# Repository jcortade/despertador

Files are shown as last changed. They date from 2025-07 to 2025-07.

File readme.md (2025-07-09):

# Alarm clock based on ESP32

This is an alarm clock based on ESP32 programmed in micropython. Its main features are:

- Four digits seven segments display. Oldie but goodie.
- Three push buttons for alarm time selection.
- LM386 audio power amplifier with a 1W speaker. It plays Tetris tune.
- LDR used to power off the display in the dark.
- PIR detector to see time in the dark and turn off the alarm.
- "Dimmable" LED using PWM ouput.
- It connects via wifi to an NTP server and synchronize automatically. It also even calculates summer/winter time!

Prototyping phase:
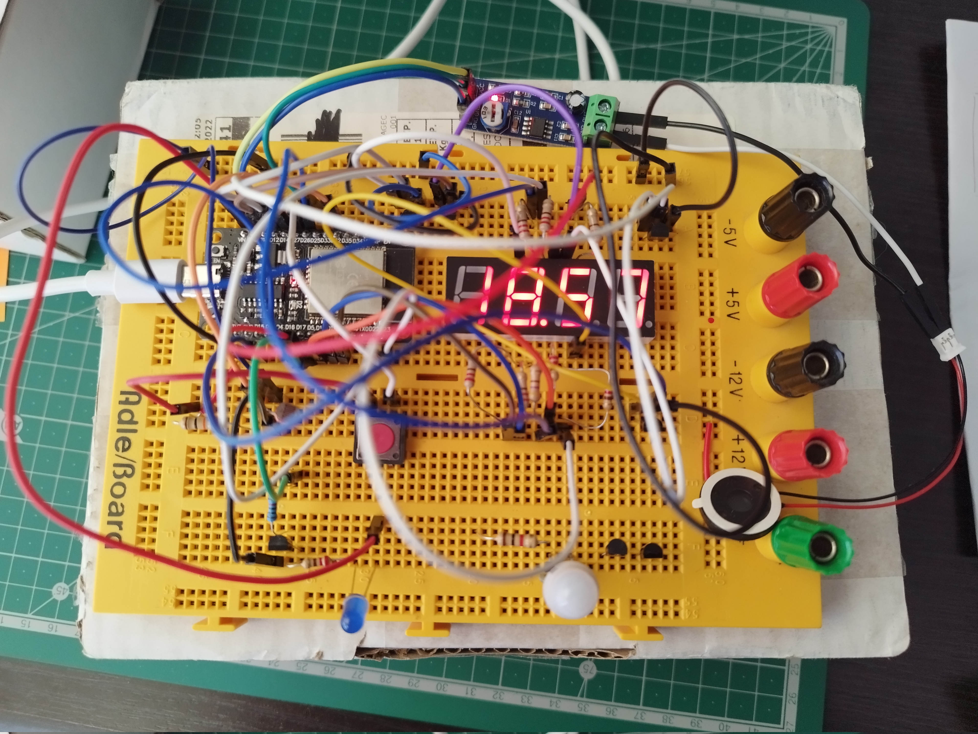
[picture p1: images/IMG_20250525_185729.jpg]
Protoboard with a mess of wiring


Preparing PCB for solder paste application:
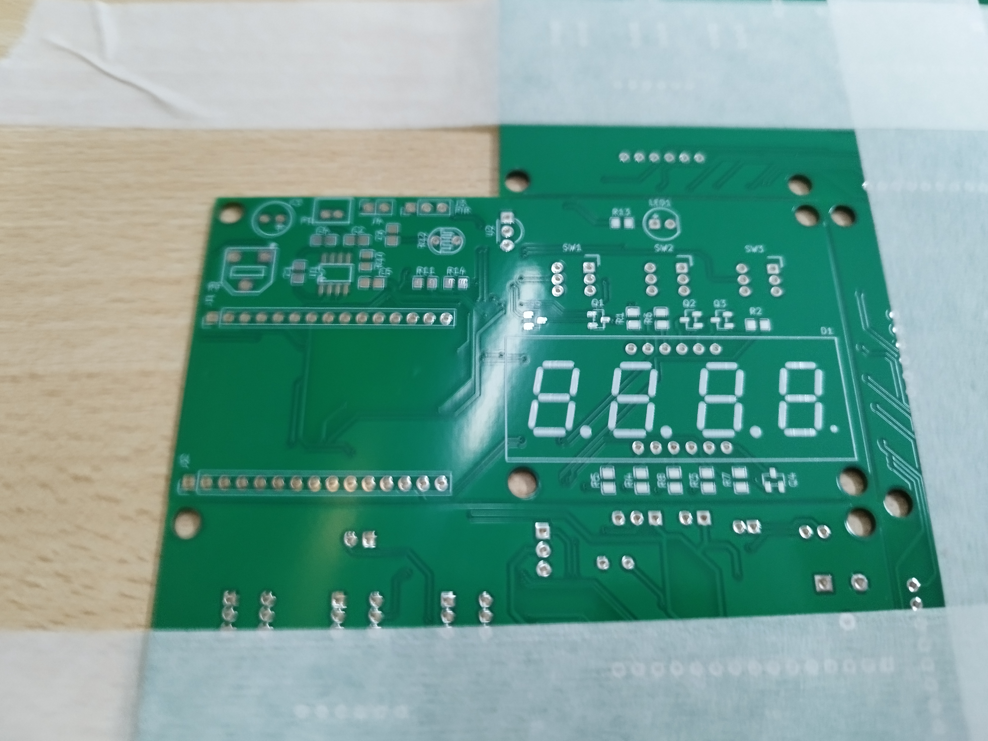
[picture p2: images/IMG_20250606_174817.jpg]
PCB


PCB with components soldered:
PCB with all components soldered

Final result:
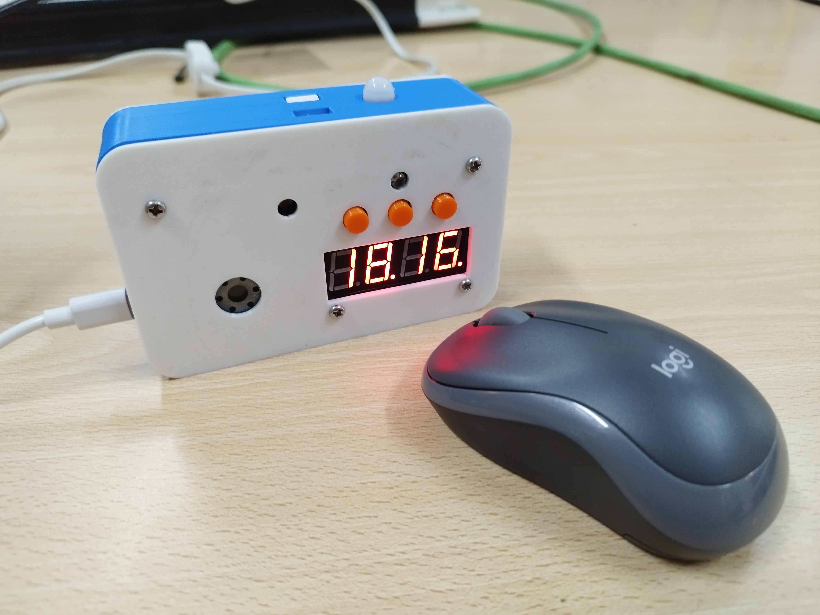
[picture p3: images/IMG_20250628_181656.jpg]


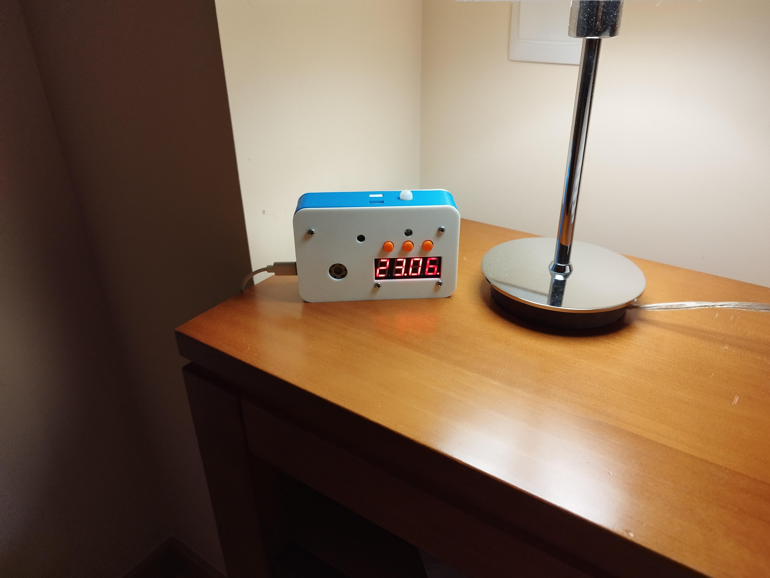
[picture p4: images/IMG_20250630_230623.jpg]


PCB was designed with kiCAD. 

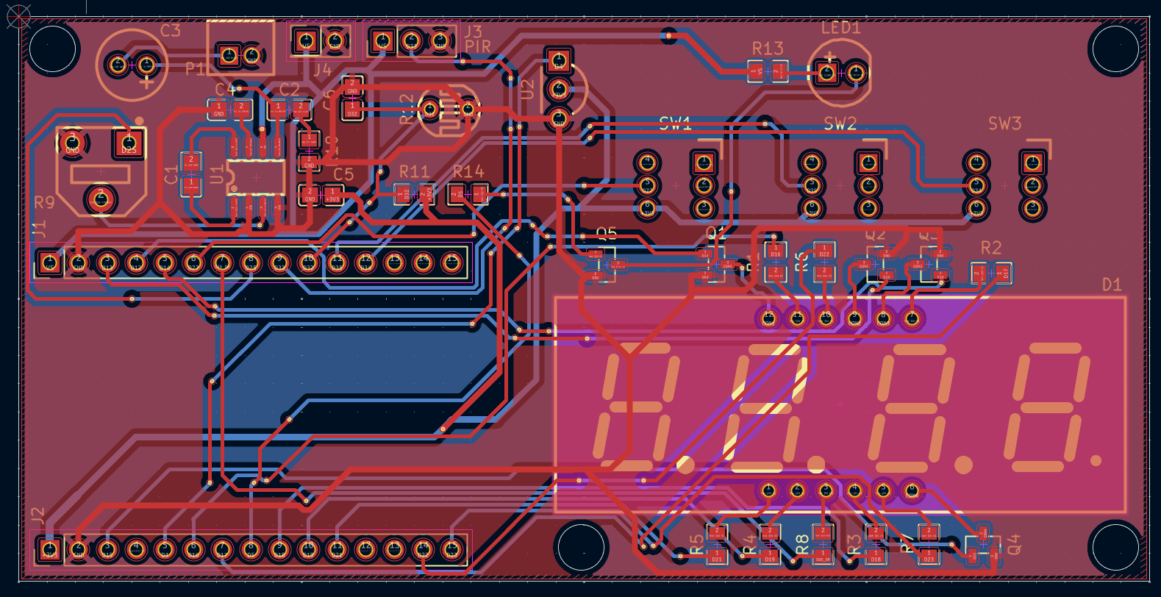
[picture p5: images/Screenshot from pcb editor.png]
PCB editor screenshot


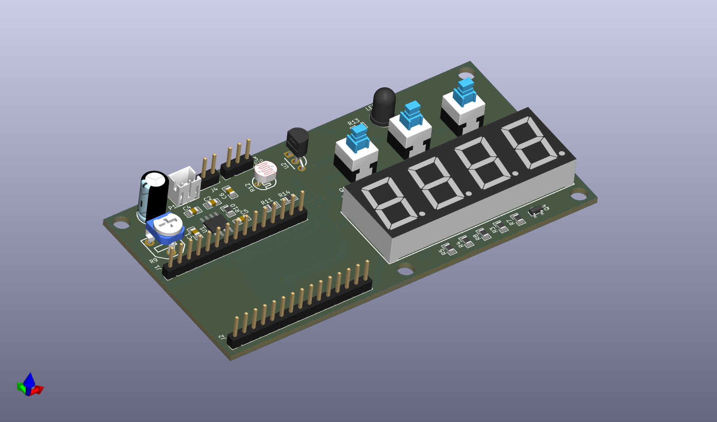
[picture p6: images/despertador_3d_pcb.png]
3D PCB visualizer screenshot


3D printed alarm clock body was designed with FreeCAD. 

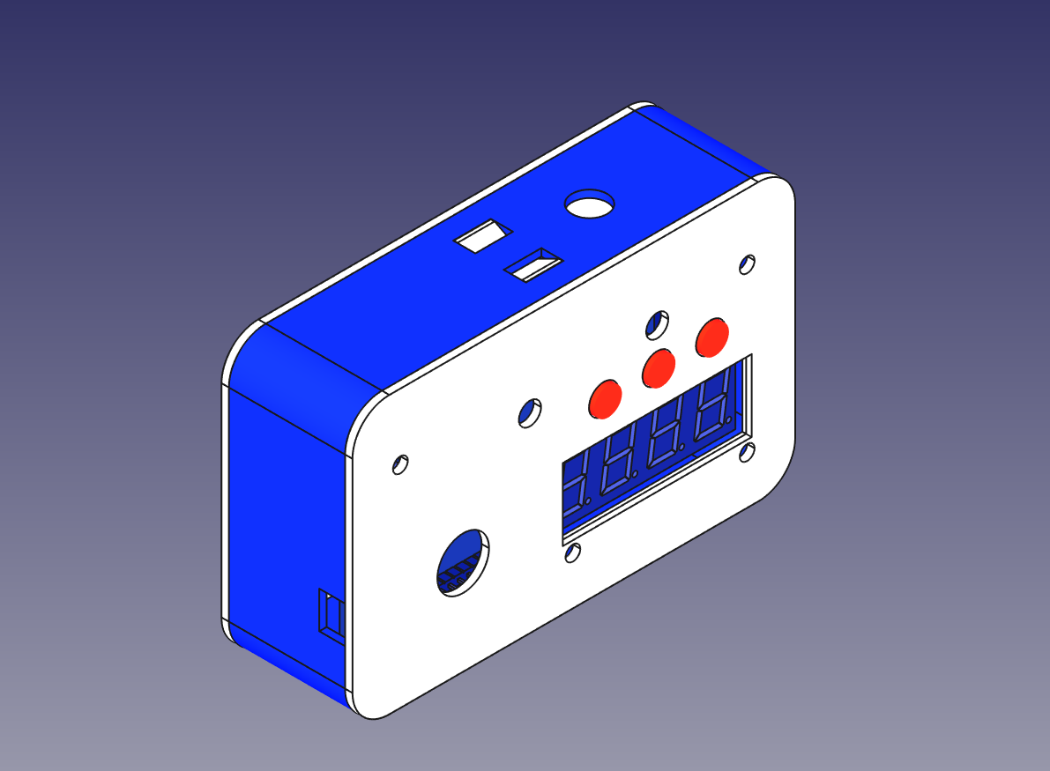
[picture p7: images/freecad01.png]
FreeCAD Screenshot 1


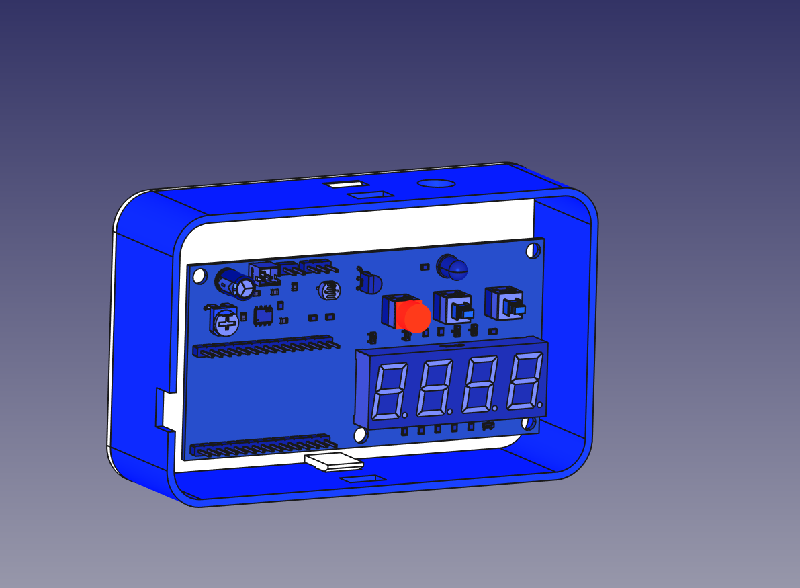
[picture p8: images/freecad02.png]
FreeCAD Screenshot 2


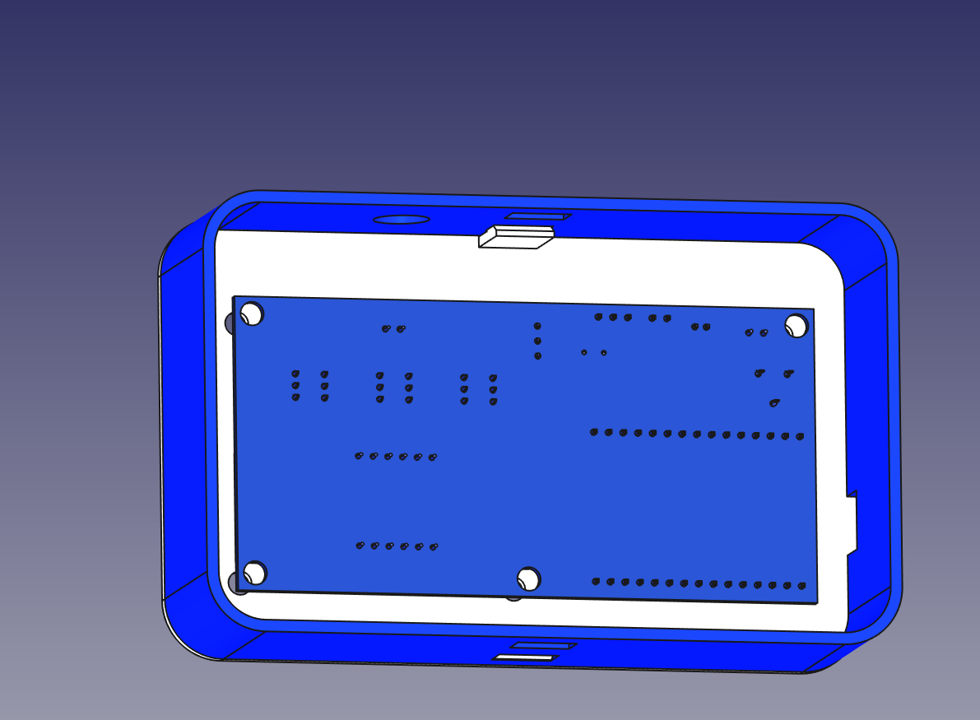
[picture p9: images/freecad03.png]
FreeCAD Screenshot 3


Inspired by this project: https://github.com/thedalles77/Raspberry-Pi-Pico-LED-Alarm-Clock

Audio player idea from here: https://circuitdigest.com/microcontroller-projects/esp32-based-audio-player

Tetris tune acknowledgements: https://assets.codeclubau.org/assets/tetris-theme.pdf

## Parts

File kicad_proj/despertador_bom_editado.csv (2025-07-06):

Reference | LCSC Part | Value | Footprint | Datasheet | Qty | LCSC Part
C1,C4 | C15850 | CL21A106KAYNNNE | easyeda2kicad:C0805 | https://lcsc.com/product-detail/Multilayer-Ceramic-Capacitors-MLCC-SMD-SMT_SAMSUNG_CL21A106KAYNNNE_10uF-106-10-25V_C15850.html | 2 | C15850
C2 | C53134 | CL21B473KBCNNNC | easyeda2kicad:C0805 | https://lcsc.com/product-detail/Multilayer-Ceramic-Capacitors-MLCC-SMD-SMT_SAMSUNG_CL21B473KBCNNNC_47nF-473-10-50V_C53134.html | 1 | C53134
C3 | C43340 | 220uF 16V 6.3*7 | easyeda2kicad:CAP-TH_BD6.3-P2.50-D1.0-FD | https://lcsc.com/product-detail/Aluminum-Electrolytic-Capacitors-Leaded_220uF-16V_C43340.html | 1 | C43340
C5,C6 | C5451689 | C0805X104K251T | easyeda2kicad:C0805 |  | 2 | C5451689
D1 | C54396 | FJ5461AH red | easyeda2kicad:LED-SEG-TH_FJ5461AH | https://lcsc.com/product-detail/Led-Segment-Display_4Bit0-56Inch-red-digital-LED-RHOS_C54396.html | 1 | C54396
LED1 | C7470729 | DY-324SVRC-H23-P-A4(FH) | easyeda2kicad:LED-TH_BD5.8-P2.54-RD |  | 1 | C7470729
P1 | C2319 | PH-2A_C2319 | easyeda2kicad:CONN-TH_2P-P2.00_PH-2A_C2319 | https://lcsc.com/product-detail/PH-Connectors_PH-2A_C2319.html | 1 | C2319
Q1,Q2,Q3,Q4 | C5236685 | BS170FTA_C5236685 | easyeda2kicad:SOT-23-3_L2.9-W1.3-P1.90-LS2.4-BR |  | 4 | C5236685
Q5 | C2150 | SS8050_C2150 | easyeda2kicad:SOT-23-3_L2.9-W1.3-P1.90-LS2.4-BR | https://lcsc.com/product-detail/Transistors-NPN-PNP_SS8050-Y1-200-350_C2150.html | 1 | C2150
R1,R2,R3,R4,R5,R6,R7,R8,R13 | C17630 | 0805W8F3300T5E | easyeda2kicad:R0805 | https://lcsc.com/product-detail/Chip-Resistor-Surface-Mount-UniOhm_330R-3300-1_C17630.html | 9 | C17630
R9 | C5205021 | RM065-103(10K) | easyeda2kicad:RES-ADJ-SMD_RM065-V1 |  | 1 | C5205021
R10 | C17415 | 0805W8F100JT5E | easyeda2kicad:R0805_NEW | https://lcsc.com/product-detail/Chip-Resistor-Surface-Mount-UniOhm_10R-10R0-1_C17415.html | 1 | C17415
R11,R14 | C17414 | 0805W8F1002T5E | easyeda2kicad:R0805 | https://lcsc.com/product-detail/Chip-Resistor-Surface-Mount-UniOhm_10KR-1002-1_C17414.html | 2 | C17414
R12 | C125626 | GL5516 | easyeda2kicad:RES-TH_L5.1-W4.3-P3.40-D0.5 | https://lcsc.com/product-detail/Photoresistors_GL5516_C125626.html | 1 | C125626
SW1,SW2,SW3 | C22363820 | PS-7054DVB-6PN | easyeda2kicad:SW-TH_6P-L7.0-W7.0-P2.00 |  | 3 | C22363820
U1 | C85119 | LM386G-S08-R | easyeda2kicad:SOP-8_L4.9-W3.9-P1.27-LS6.0-BL | https://lcsc.com/product-detail/Audio-OpAmps_LM386G-S08-R_C85119.html | 1 | C85119
U2 | C5692995 | TMP36GT9Z(UMW) | easyeda2kicad:TO-92-3_L4.8-W3.7-P2.54-L |  | 1 | C5692995

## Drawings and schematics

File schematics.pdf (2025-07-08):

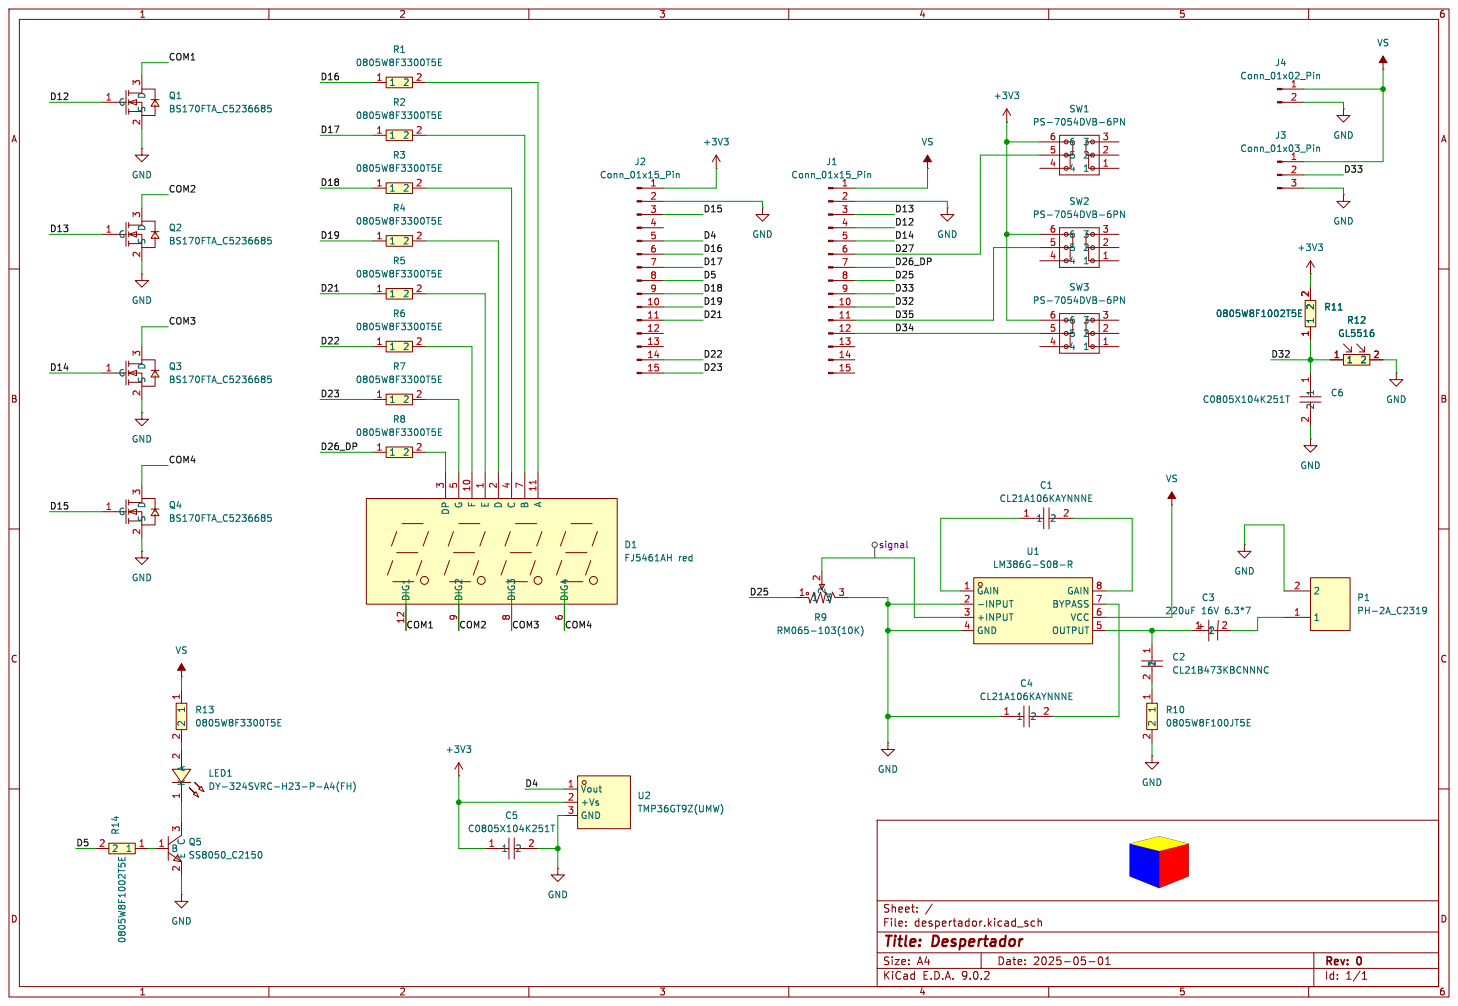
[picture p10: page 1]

Id: 1/1 Title: Despertador File: despertador.kicad_sch Sheet: /

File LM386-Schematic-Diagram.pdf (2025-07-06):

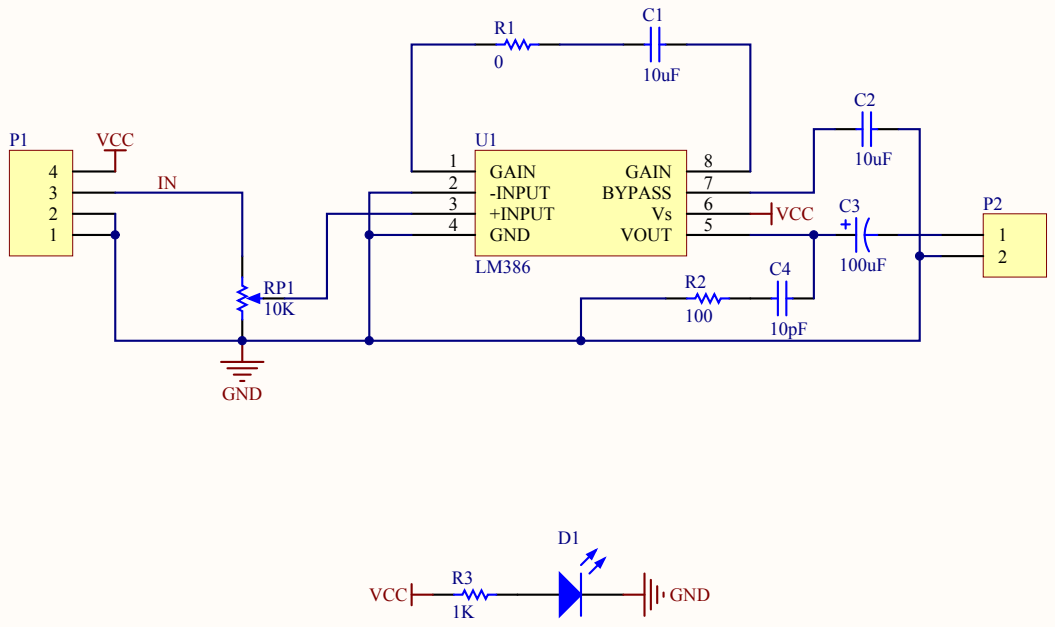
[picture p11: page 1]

Comment | Description | Designator | Footprint | LibRef | Quantity
10uF | Capacitor | C1, C2 | 0805 | CAP | 2
100uF | Polarized Capacitor (Radial) | C3 | CAPPR2-5x6.8 | Cap Pol1 | 1
10pF | Capacitor | C4 | 0805 | CAP | 1
LED | Typical INFRARED GaAs LED | D1 | LED-0805 | LED | 1
Header 4 | Header, 4-Pin | P1 | HDR1X4 | Header 4 | 1
Header 2 | Header, 2-Pin | P2 | Terminal-5.08-2P | Header 2 | 1
0 | Semiconductor Resistor | R1 | 0805 | RES | 1
100 | Semiconductor Resistor | R2 | 0805 | RES | 1
1K | Semiconductor Resistor | R3 | 0805 | RES | 1
10K | Potentiometer | RP1 | RM063 | RPot | 1
LM386 | | U1 | SOIC8 | LM386 | 1

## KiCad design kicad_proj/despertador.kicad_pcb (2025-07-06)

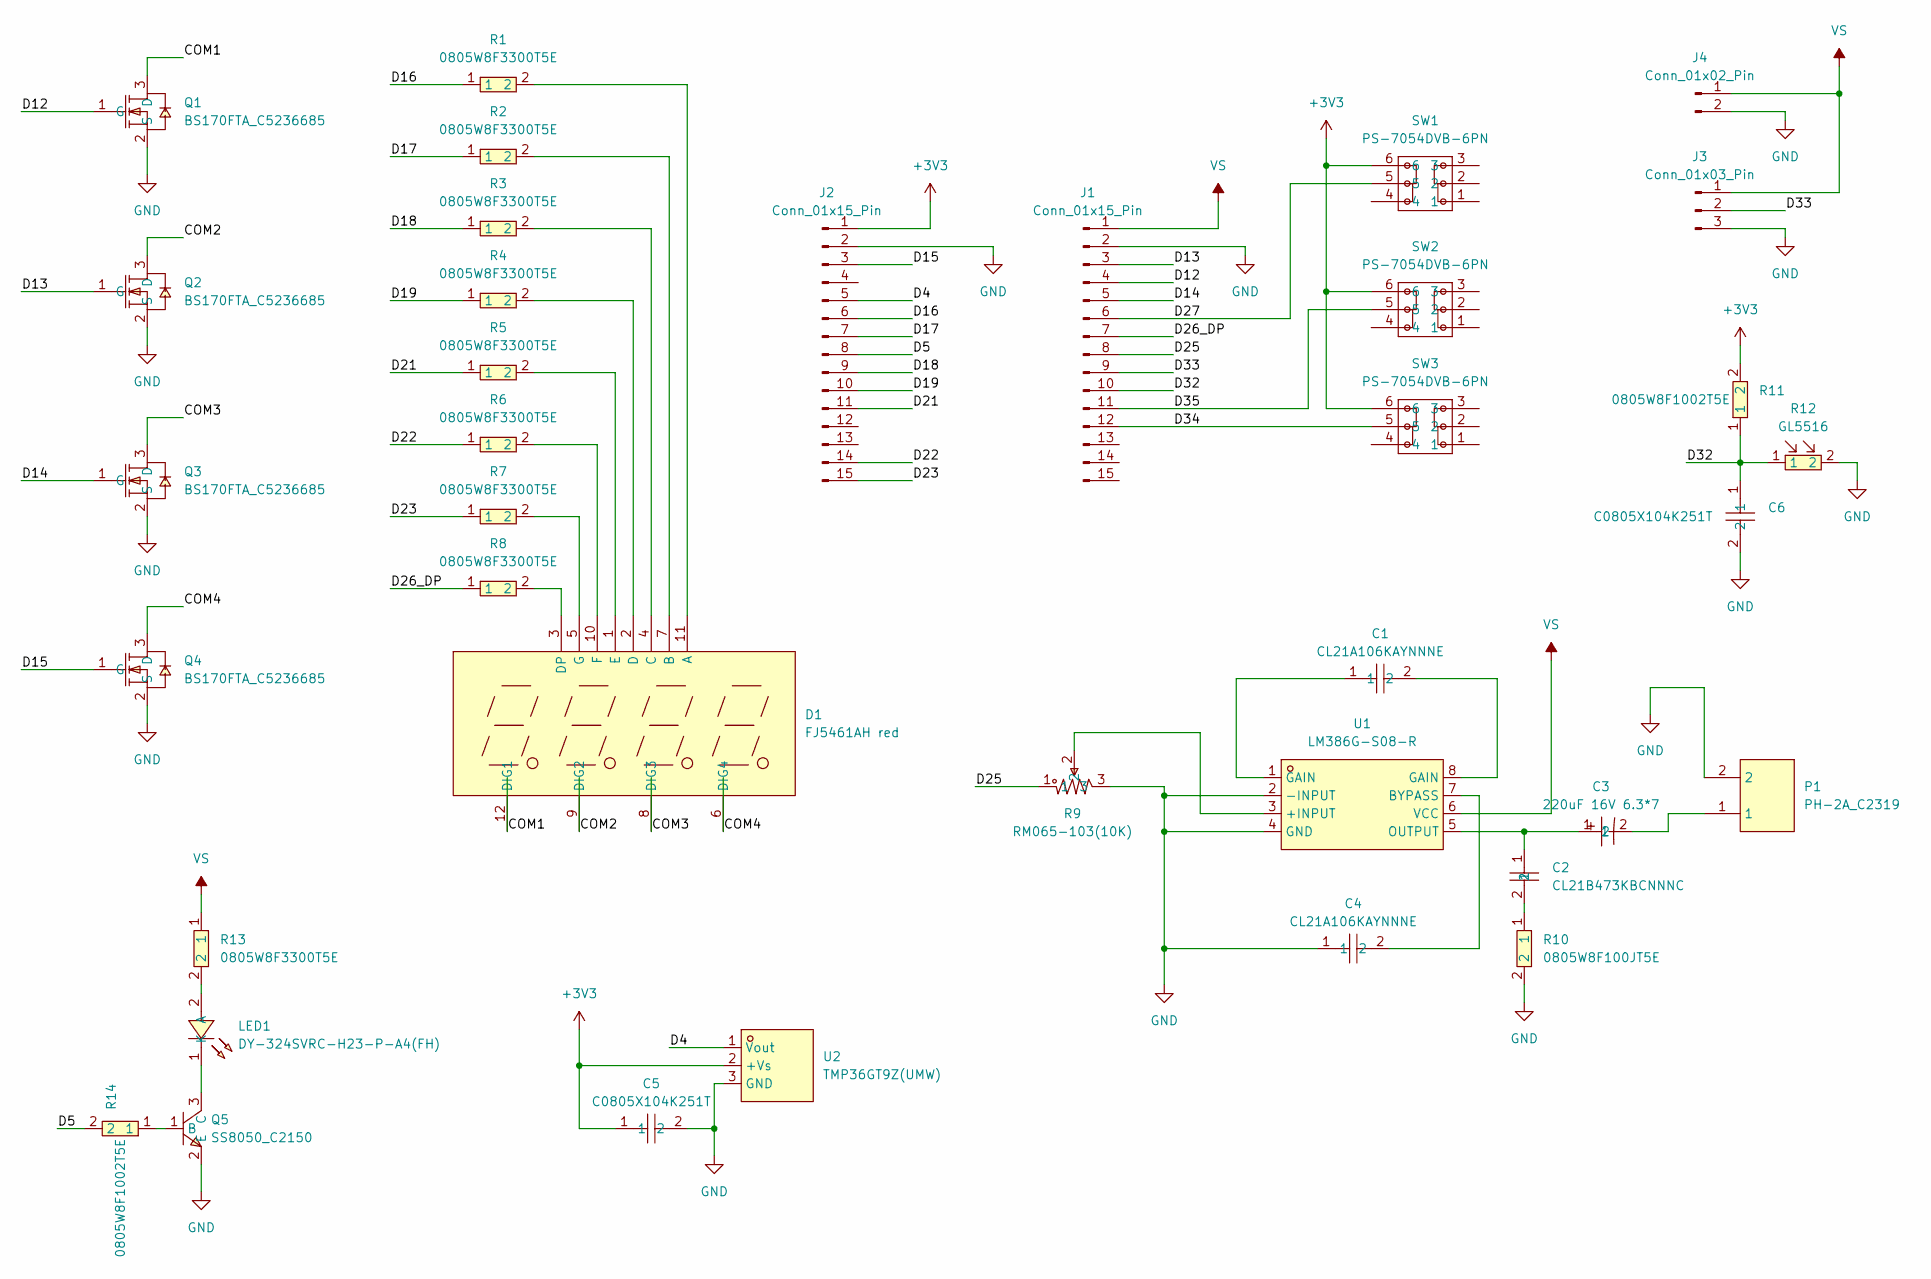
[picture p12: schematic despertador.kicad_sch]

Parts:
C1, C4: CL21A106KAYNNNE; C0805; LCSC Part C15850
C2: CL21B473KBCNNNC; C0805; LCSC Part C53134
C3: 220uF 16V 6.3*7; CAP-TH_BD6.3-P2.50-D1.0-FD; LCSC Part C43340
C5, C6: C0805X104K251T; C0805; LCSC Part C5451689
D1: FJ5461AH red; LED-SEG-TH_FJ5461AH; LCSC Part C54396
J1, J2: Conn_01x15_Pin; PinHeader_1x15_P2.54mm_Vertical
J3: Conn_01x03_Pin; PinHeader_1x03_P2.54mm_Vertical
J4: Conn_01x02_Pin; PinHeader_2x01_P2.54mm_Vertical
LED1: DY-324SVRC-H23-P-A4(FH); LED-TH_BD5.8-P2.54-RD; LCSC Part C7470729
P1: PH-2A_C2319; CONN-TH_2P-P2.00_PH-2A_C2319; LCSC Part C2319
Q1, Q2, Q3, Q4: BS170FTA_C5236685; SOT-23-3_L2.9-W1.3-P1.90-LS2.4-BR; LCSC Part C5236685
Q5: SS8050_C2150; SOT-23-3_L2.9-W1.3-P1.90-LS2.4-BR; LCSC Part C2150
R1, R2, R3, R4, R5, R6, R7, R8, R13: 0805W8F3300T5E; R0805; LCSC Part C17630
R9: RM065-103(10K); RES-ADJ-SMD_RM065-V1; LCSC Part C5205021
R10: 0805W8F100JT5E; R0805_NEW; LCSC Part C17415
R11, R14: 0805W8F1002T5E; R0805; LCSC Part C17414
R12: GL5516; RES-TH_L5.1-W4.3-P3.40-D0.5; LCSC Part C125626
SW1, SW2, SW3: PS-7054DVB-6PN; SW-TH_6P-L7.0-W7.0-P2.00; LCSC Part C22363820
U1: LM386G-S08-R; SOP-8_L4.9-W3.9-P1.27-LS6.0-BL; LCSC Part C85119
U2: TMP36GT9Z(UMW); TO-92-3_L4.8-W3.7-P2.54-L; LCSC Part C5692995

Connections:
+3V3: C5.1, J2.1, R11.2, SW1.6, SW2.6, SW3.6, U2.2 (+Vs)
/COM1: D1.12 (DIG1), Q1.3 (D)
/COM2: D1.9 (DIG2), Q2.3 (D)
/COM3: D1.8 (DIG3), Q3.3 (D)
/COM4: D1.6 (DIG4), Q4.3 (D)
/D4: J2.5, U2.1 (Vout)
/D5: J2.8, R14.2
/D12: J1.4, Q1.1 (G)
/D13: J1.3, Q2.1 (G)
/D14: J1.5, Q3.1 (G)
/D15: J2.3, Q4.1 (G)
/D16: J2.6, R1.1
/D17: J2.7, R2.1
/D18: J2.9, R3.1
/D19: J2.10, R4.1
/D21: J2.11, R5.1
/D22: J2.14, R6.1
/D23: J2.15, R7.1
/D25: J1.8, R9.1
/D26_DP: J1.7, R8.1
/D27: J1.6, SW1.5
/D32: C6.1, J1.10, R11.1, R12.1
/D33: J1.9, J3.2
/D34: J1.12, SW3.5
/D35: J1.11, SW2.5
GND: C4.1, C5.2, C6.2, J1.2, J2.2, J3.3, J4.2, P1.2, Q1.2 (S), Q2.2 (S), Q3.2 (S), Q4.2 (S), Q5.2 (E), R9.3, R10.2, R12.2, U1.2 (-INPUT), U1.4 (GND), U2.3 (GND)
unnamed: C1.1, U1.1 (GAIN)
unnamed: C1.2, U1.8 (GAIN)
unnamed: C2.2, R10.1
unnamed: C3.2, P1.1
unnamed: D1.11 (A), R1.2
unnamed: D1.7 (B), R2.2
unnamed: D1.4 (C), R3.2
unnamed: D1.2 (D), R4.2
unnamed: D1.3 (DP), R8.2
unnamed: D1.1 (E), R5.2
unnamed: D1.10 (F), R6.2
unnamed: D1.5 (G), R7.2
unnamed: LED1.2 (A), R13.2
unnamed: LED1.1 (K), Q5.3 (C)
unnamed: Q5.1 (B), R14.1
unnamed: R9.2, U1.3 (+INPUT)
unnamed: C4.2, U1.7 (BYPASS)
unnamed: C2.1, C3.1, U1.5 (OUTPUT)
VS: J1.1, J3.1, J4.1, R13.1, U1.6 (VCC)

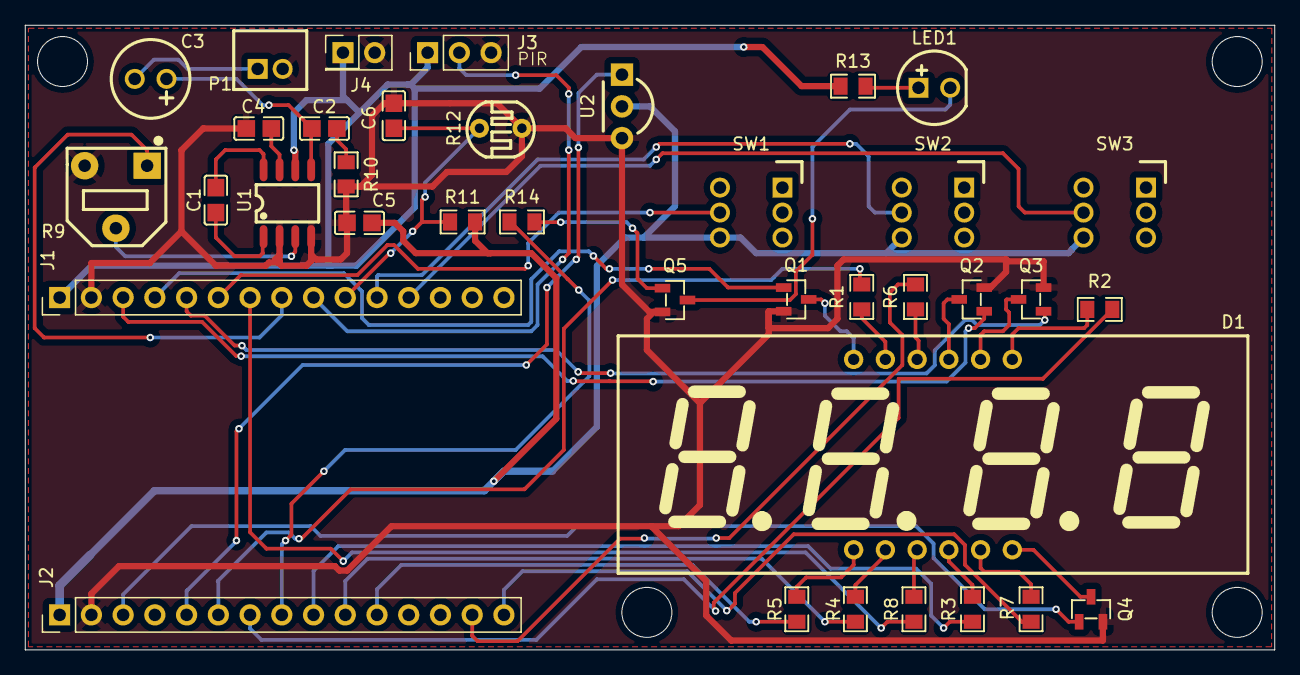
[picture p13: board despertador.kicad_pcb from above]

Board: 2 copper layers, 100.0 x 50.0 mm, 37 parts (0 on the bottom side), 45 nets.

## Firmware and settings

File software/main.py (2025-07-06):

from machine import Pin, ADC, Timer, PWM, RTC
import time
import network
from basicas import *
from hora_local import *
from seven_segments import *
import uasyncio as asyncio
from sounds import *

last_execution_hour = -1
year = 0
month = 0
day = 0
hour = 0
minute = 0
second = 0

alarm_hour = 6
alarm_minute = 0
enable_alarm = 0	# Goes high when user activates alarm
flag_activate_alarm = 0 # Goes high when alarm time is reached
state = "IDLE"

flag_1s = 0
flag_500ms = 0
square_500ms = 0

#PIR - Digital Input (GPIO33) <- MPIR sensor	
PIR = Pin(33, Pin.IN, Pin.PULL_DOWN)     # create input pin on GPIO33


# Analog Input (GPIO32) <- LDR
EA32 = ADC(Pin(32)) # LDR input
EA32.atten(ADC.ATTN_11DB)  # Full range of 0 to 3.3V

# Set up ADC on GPIO4 <- Temperature	
EA4 = ADC(4)



#SW1 - Digital Input (GPIO27) <- Main button
main_button = Pin(27, Pin.IN, Pin.PULL_DOWN)
debounce_time = 250  # ms
last_time = 0
flag_main_button = 0

def main_button_handler(pin):
    global last_time, flag_main_button
    now = time.ticks_ms()

    if abs(now - last_time) > debounce_time:
        #if pin.value() == 1:  # Confirm button is still pressed (optional)
            print("Debounced button press!")
            flag_main_button = 1
    last_time = now

main_button.irq(trigger=Pin.IRQ_RISING, handler=main_button_handler)

#SW2 - Digital Input (GPIO35) <- Minus button
minus_button = Pin(35, Pin.IN)
last_time_minus = 0
flag_minus_button = 0

def minus_button_handler(pin):
    global last_time_minus, flag_minus_button
    now = time.ticks_ms()

    if abs(now - last_time_minus) > debounce_time:
        #if pin.value() == 1:  # Confirm button is still pressed (optional)
            print("Debounced button press!")
            flag_minus_button = 1
    last_time_minus = now

minus_button.irq(trigger=Pin.IRQ_FALLING, handler=minus_button_handler)

#SW3 - Digital Input (GPIO34) <- Plus button
plus_button = Pin(34, Pin.IN)
last_time_plus = 0
flag_plus_button = 0

def plus_button_handler(pin):
    global last_time_plus, flag_plus_button
    now = time.ticks_ms()

    if abs(now - last_time_plus) > debounce_time:
        #if pin.value() == 1:  # Confirm button is still pressed (optional)
            print("Debounced button press!")
            flag_plus_button = 1
    last_time_plus = now

plus_button.irq(trigger=Pin.IRQ_RISING, handler=plus_button_handler)

# Digital Output (GPIO5) -> LED
DO5 = Pin(5, Pin.OUT)    # LED output
led_pwm = PWM(DO5, freq=1000)
led_duty = 0
led_pwm.duty_u16(led_duty)

# Set up PWM on GPIO25 -> SPEAKER
speaker_pin = Pin(25, Pin.OUT)
speaker_pwm = PWM(speaker_pin, freq=1000, duty_u16=0)  # 32768 -> 50% duty (silence initially)
freq = 1000

# TIMERS DEFINITION
t_1s = Timer(-1)  # Use virtual timer (-1)
t_500ms = Timer(-2) # Use virtual timer (-2)

def funcion_1s(t):
    global EA32_uv, EA32, EA4, volts_ldr, flag_1s
    EA32_uv = EA32.read_uv() #microvoltios    

    volts_ldr = scale_ai(EA32_uv, 0, 3.3)
    print("Volts:", volts_ldr)
    
    #EA4_uv = EA4.read_uv() #microvoltios    
    #print("microvoltios:", EA4_uv)
    
    #temperatura = scale_ai(EA4_uv, -50, 280)    
    #print("Temperatura:", temperatura)

    flag_1s = 1

def funcion_500ms(t):
    global flag_500ms, square_500ms
    
    flag_500ms = 1
    
    if square_500ms==0:
        square_500ms=1
    else:
        square_500ms=0
    

# periodic at 1s
t_1s.init(mode=Timer.PERIODIC, freq=1, callback=funcion_1s)
# periodic at 2Hz
t_500ms.init(mode=Timer.PERIODIC, freq=2, callback=funcion_500ms)


    

def idle(hora_display):
    global flag_main_button, flag_plus_button, flag_minus_button, enable_alarm
    
    if volts_ldr>2.5 and not PIR.value():
        display_all((' ',' ',' ',' '), (0,0,0,0))
    else:        
        display_all(hora_display, (0,1,0,enable_alarm))
    
    flag_plus_button=0
    flag_minus_button=0    
    
    if flag_main_button == 1 and flag_activate_alarm==0:
        if enable_alarm==1:
            print("ALARMA DESACTIVADA")
            enable_alarm = 0
            flag_main_button = 0
            return "IDLE"
        else:
            print("CAMBIA A HORAS")
            enable_alarm = 1
            flag_main_button = 0
            return "HOURS"
    return "IDLE"

def hours_selection(hora_display):
    global flag_main_button, flag_plus_button, flag_minus_button, alarm_hour
    
    if square_500ms==1:
        display_all((' ',' ',' ',' '), (0,1,0,0))
    else:        
        display_all((str(alarm_hour//10),str(alarm_hour%10),' ',' '), (0,1,0,0))
    
    if flag_plus_button==1:
        if alarm_hour<23:
            alarm_hour = alarm_hour + 1
        else:
            alarm_hour = 0            
        flag_plus_button = 0
    
    if flag_minus_button==1:
        if alarm_hour>0:
            alarm_hour = alarm_hour - 1
        else:
            alarm_hour = 23            
        flag_minus_button = 0
        
    if flag_main_button == 1:
        print("CAMBIA A MINUTOS")
        flag_main_button = 0        
        return "MINUTES"
    return "HOURS"

def minutes_selection(hora_display):
    global flag_main_button, flag_plus_button, flag_minus_button, alarm_hour,alarm_minute
    
    if square_500ms==1:
        display_all((str(alarm_hour//10),str(alarm_hour%10),' ',' '), (0,1,0,0))
    else:        
        display_all((str(alarm_hour//10),str(alarm_hour%10),str(alarm_minute//10),str(alarm_minute%10)), (0,1,0,0))

    if flag_plus_button==1:
        if alarm_minute<59:
            alarm_minute = alarm_minute + 1
        else:
            alarm_minute = 0    
        flag_plus_button = 0
    
    if flag_minus_button==1:
        if alarm_minute>0:
            alarm_minute = alarm_minute - 1
        else:
            alarm_minute = 59
        flag_minus_button = 0


    if flag_main_button == 1:
        print("CAMBIA A IDLE")
        flag_main_button = 0  
        return "IDLE"
    return "MINUTES"

# Mapeo de estados a funciones
states = {
    "IDLE": idle,
    "HOURS": hours_selection,
    "MINUTES": minutes_selection,
}


#INTRO
for i in range(10):
    display_character(' ', 3, 1)
    display_character(str(9-i), 3, 1)
    led_duty = led_duty + 1000
    led_pwm.duty_u16(led_duty)
    time.sleep(0.2)
   
led_duty = 0
led_pwm.duty_u16(led_duty)
speaker_pwm.duty_u16(32768)
speaker_pwm.freq(440)
time.sleep(0.5)

speaker_pwm.duty_u16(0)



while True:
    
    synchronize()
    
    year, month, day, hour, minute, second = get_current_time()
    
    if (hour//10)>0:
        hora_display = (str(hour//10),str(hour%10),str(minute//10),str(minute%10))
    else:
        hora_display = (' ',str(hour%10),str(minute//10),str(minute%10))
    
    state = states[state](hora_display)  # Ejecuta la función del estado actual y actualiza el estado
    
    if PIR.value():
        print("Movement detectected!!")
            
    if hour==alarm_hour and minute==alarm_minute and second==0 and enable_alarm==1:
        flag_activate_alarm = 1
    
    if main_button.value() == 0 or PIR.value():
        flag_activate_alarm = 0
    
    if flag_activate_alarm == 1:

        for tone, length in zip(melody, rhythm):

            if led_duty>=65535:
                led_duty = 0
            else:
                led_duty = led_duty + 100
            if PIR.value():
                break
            led_pwm.duty_u16(led_duty)
            speaker_pwm.duty_u16(32768)
            speaker_pwm.freq(tones[tone])
            time.sleep(tempo/length)
    else:
        led_duty = 0
        led_pwm.duty_u16(led_duty)
        speaker_pwm.duty_u16(0)  # 0% duty 
        


    

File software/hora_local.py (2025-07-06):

import ntptime
import time
import network
from machine import RTC
import uasyncio as asyncio

from wifi import *
from wifi_functions import *

# Configuración del servidor NTP
NTP_SERVER = "es.pool.ntp.org"

# Zona horaria (en horas)
TIMEZONE_OFFSET = 1  # Para España (CET) es +1

last_execution_hour = -1
year = 0
month = 0
day = 0
hour = 0
minute = 0
second = 0


# Función para ajustar la hora según el horario de verano/invierno
def adjust_for_daylight_saving(year, month, day, hour):
    # En España, el horario de verano comienza el último domingo de marzo y termina el último domingo de octubre
    if month > 3 and month < 10:
        if (hour+1+TIMEZONE_OFFSET)<24:
            return hour + 1 + TIMEZONE_OFFSET# Horario de verano (CEST)
        else:
            return (hour + 1 + TIMEZONE_OFFSET - 24)
        
    elif month == 3:
        # Último domingo de marzo
        last_sunday = 31 - (5 * year // 4 + 4) % 7
        if day >= last_sunday and hour >= 2:
            if (hour+1+TIMEZONE_OFFSET)<24:
                return hour + 1 + TIMEZONE_OFFSET
            else:
                return (hour + 1 + TIMEZONE_OFFSET - 24)
            
    elif month == 10:
        # Último domingo de octubre
        last_sunday = 31 - (5 * year // 4 + 1) % 7
        if day < last_sunday or (day == last_sunday and hour < 3):
            if (hour+1+TIMEZONE_OFFSET)<24:
                return hour + 1 + TIMEZONE_OFFSET
            else:
                return (hour + 1 + TIMEZONE_OFFSET - 24)
        
    # Horario de invierno (CET)
    if (hour+TIMEZONE_OFFSET)<24:
        return hour + TIMEZONE_OFFSET 
    else:
        return (hour + TIMEZONE_OFFSET - 24)

# Función para obtener la hora actual
def get_current_time():
    #print("Local time after synchronization：%s" %str(time.localtime()))
    rtc = RTC()
    year, month, day, weekday, hour, minute, second, _ = rtc.datetime()
    hour_adjusted = adjust_for_daylight_saving(year, month, day, hour)
    return (year, month, day, hour_adjusted, minute, second)

# Función para poner en hora con sincronización 
def set_current_time():
    connect_wifi()

    ntptime.host = NTP_SERVER
    #ntptime.settime()
    
    # Número máximo de reintentos
    max_retries = 5

    for i in range(max_retries):
        try:
            ntptime.settime()
            print("Hora sincronizada correctamente")
            break  # Sale del bucle si tiene éxito
        except OSError as e:
            print(f"Intento {i + 1} fallido:", e)
            await uasyncio.sleep(5) #time.sleep(5)  # Espera 5 segundos antes de reintentar
    else:
        print("No se pudo sincronizar la hora después de varios intentos")
    
    disconnect_wifi()

def synchronize():
    
    global last_execution_hour
    global year, month, day, hour, minute, second
    
    ntptime.host = NTP_SERVER
    
    # Número máximo de reintentos sincronización NTP
    max_retries = 5
    
    #while True:
        
    # Verifica si son las 12. A las 12 se sincroniza
    if (hour != last_execution_hour): # and (hour==12):
        
        connect_wifi()

        for i in range(max_retries):
            try:
                ntptime.settime()
                print("Hora sincronizada correctamente")
                break  # Sale del bucle si tiene éxito
            except OSError as e:
                print(f"Intento {i + 1} fallido:", e)
                time.sleep(3)
        else:
            print("No se pudo sincronizar la hora después de varios intentos")
        
        
        disconnect_wifi()
        last_execution_hour = hour
            

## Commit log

2025-07-06 BOM.txt deleted
2025-07-08 images and schematics added
